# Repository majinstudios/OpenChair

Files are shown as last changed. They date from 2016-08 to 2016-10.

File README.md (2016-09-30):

# OpenChair

With OpenChair we want to create the first wheelchair development platform in which users can code or design the adaptations necessary to fit their needs.

In order to do so, we modified a manual wheelchair to convert it into an electric one, designed highly customizable armrests and developed a controller board with BLE to allow users to build and control the wheelchair in the manner that best suits them.

For further information and build instructions, please check [this page](https://hackaday.io/project/13347-openchair).

Licenses
---------
Software: GPL v3
Mechanical: Creative Commons Attribution-ShareAlike 4.0 International (CC BY-SA 4.0)

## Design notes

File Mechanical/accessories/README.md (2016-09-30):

# OpenChair: how to create a custom accessory
Inside the utilities folder you may find the FreeCad file (and also stl & step files) of both the male and female hitches needed to create custom accessories.

Using the female hitch, you can adapt the surface you want to the existing accessories.

With the male hitch, you can create a custom accessory that will fit the OpenChair armrest.

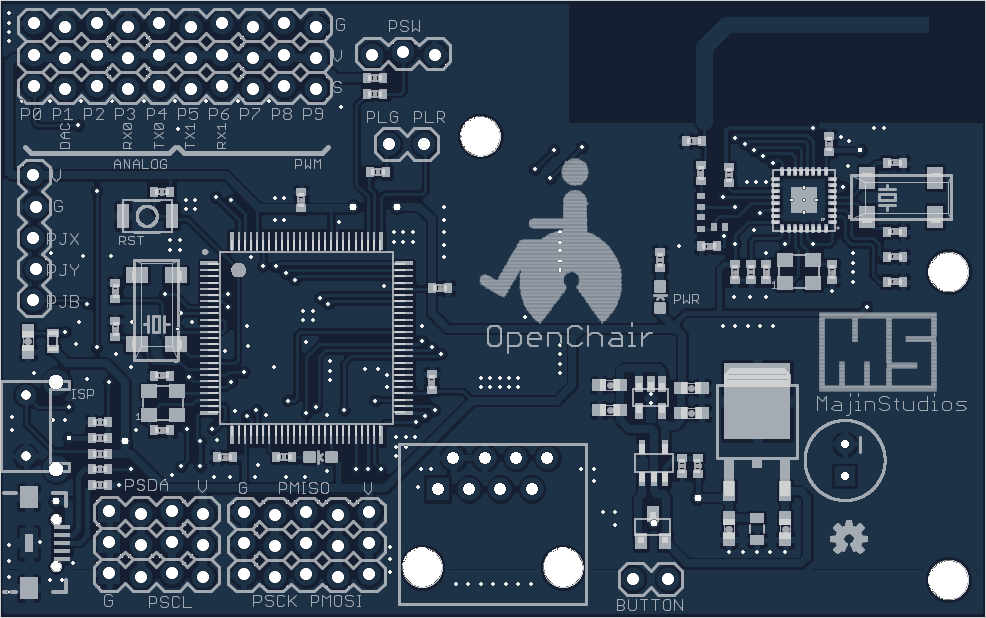
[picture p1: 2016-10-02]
Hardware/Silkscreen/OpenChair1_Top.png

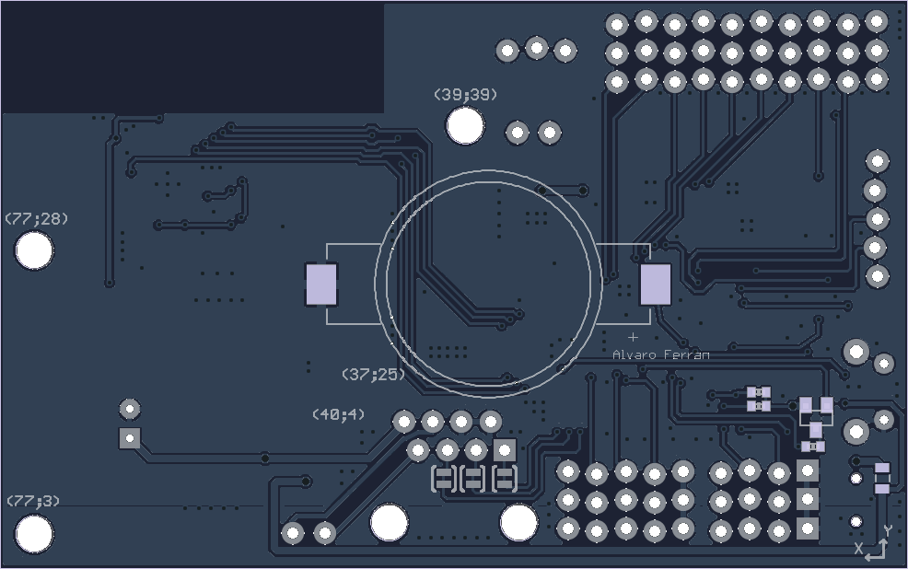
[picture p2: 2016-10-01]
Hardware/Silkscreen/OpenChair2_Bottom.png

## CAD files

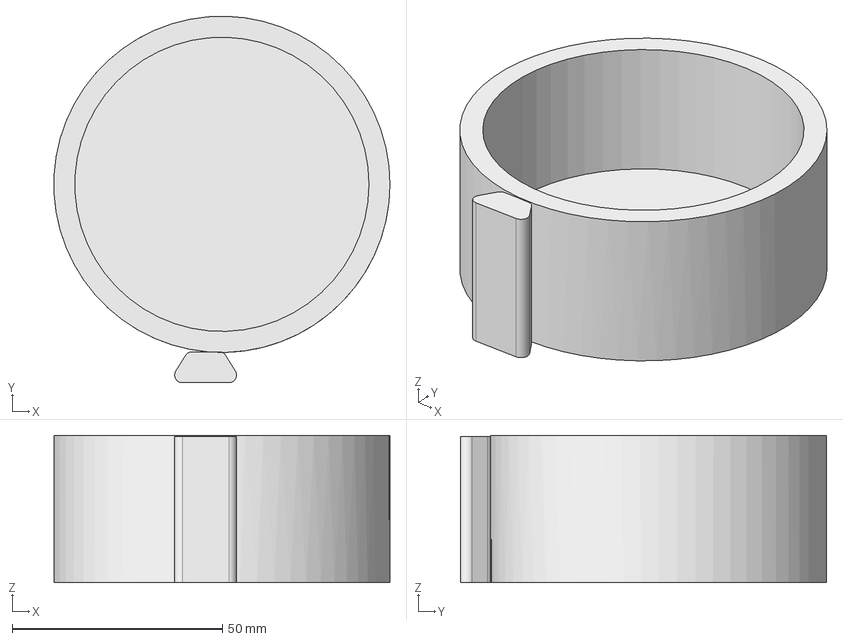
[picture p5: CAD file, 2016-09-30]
Mechanical/accessories/Can holder/can_holder.step
79.9 x 87.2 x 35.0 mm

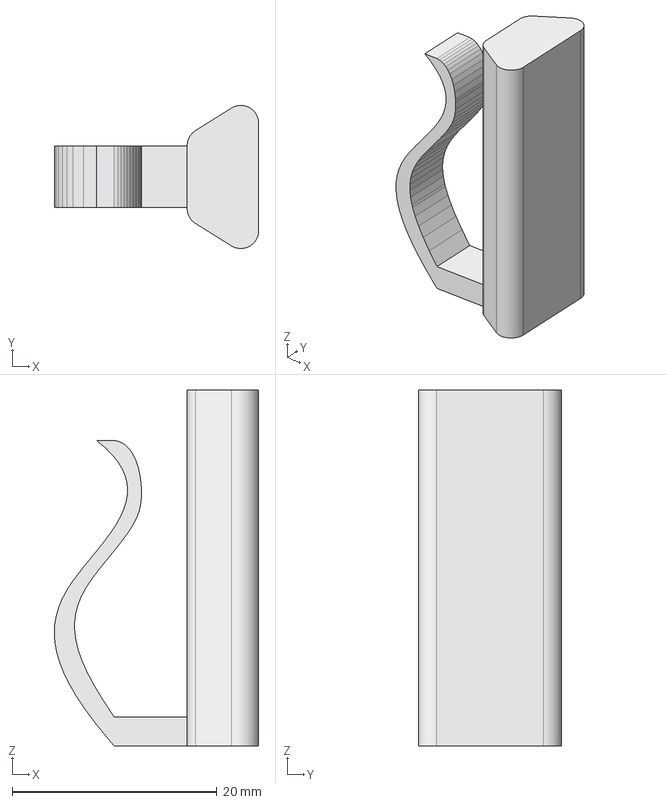
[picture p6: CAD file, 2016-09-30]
Mechanical/accessories/Clip/clip.step
20.0 x 14.0 x 34.8 mm

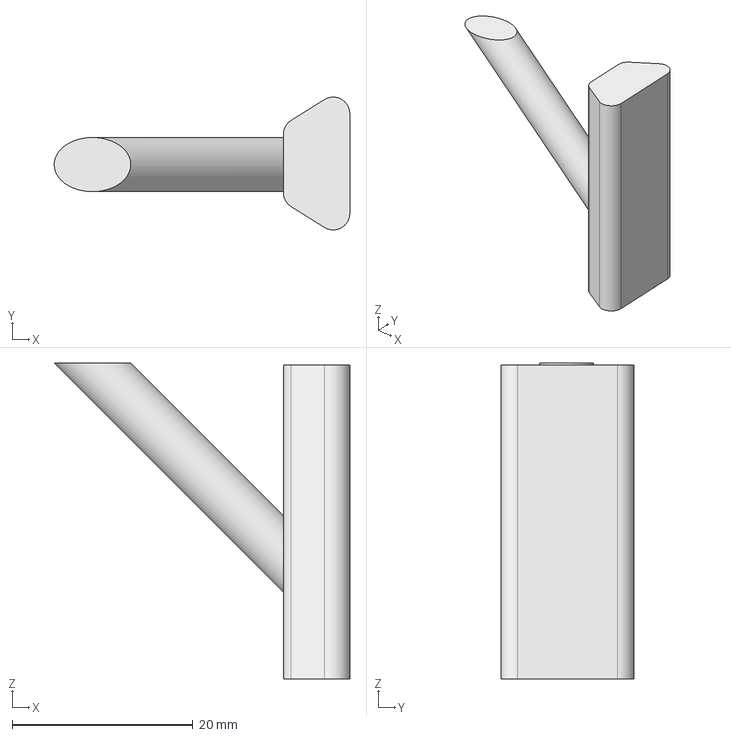
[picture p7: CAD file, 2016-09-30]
Mechanical/accessories/Hook/hook.step
32.7 x 14.7 x 35.0 mm

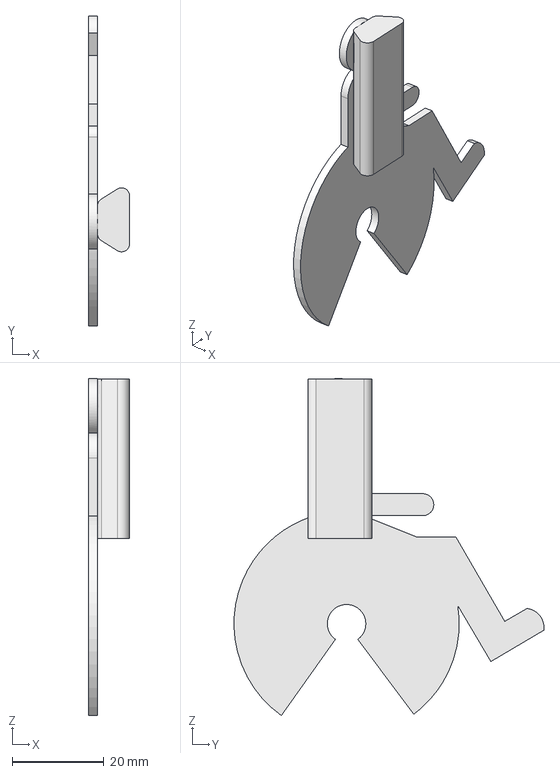
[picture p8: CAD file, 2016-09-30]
Mechanical/accessories/Logo accessory/logo.step
8.98 x 67.7 x 73.6 mm

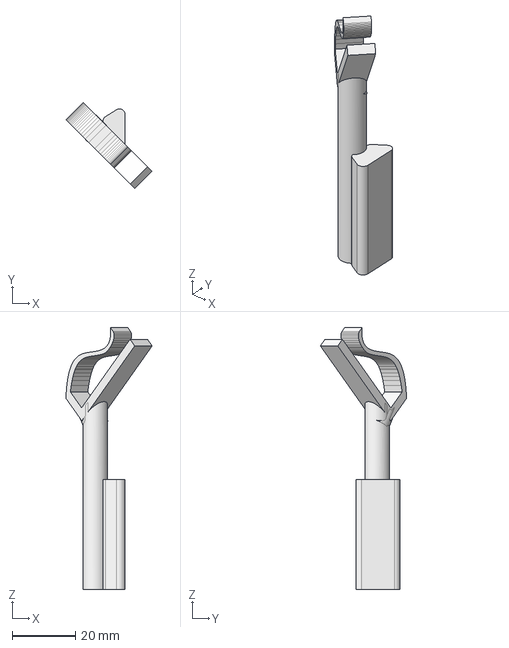
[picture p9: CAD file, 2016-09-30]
Mechanical/accessories/Mobile holder/mobile_holder.step
27.3 x 27.3 x 82.8 mm

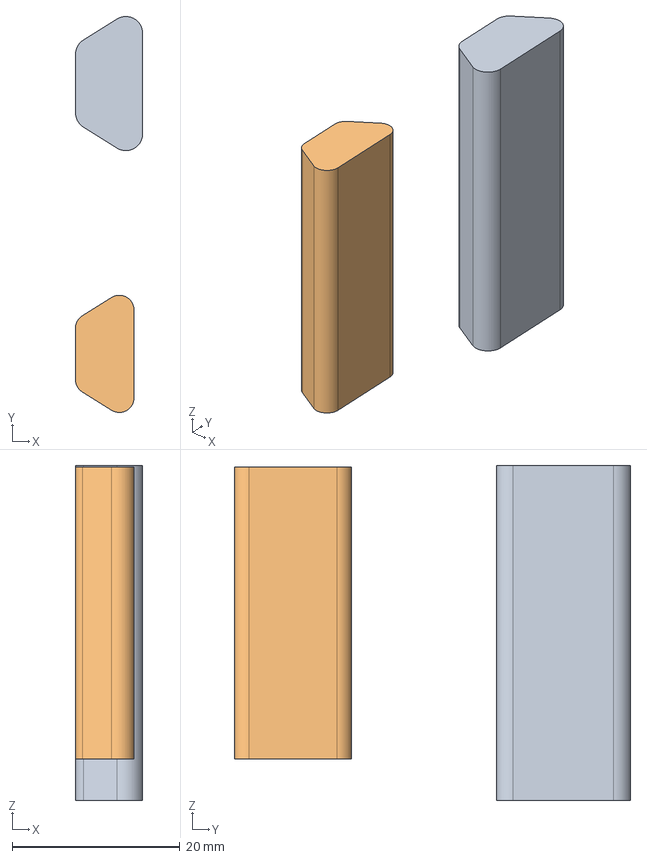
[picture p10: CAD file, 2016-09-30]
Mechanical/accessories/Utilities/Hitch_male_and_female.FCStd
8.02 x 47.2 x 40.0 mm
Hitch female
Hitch male

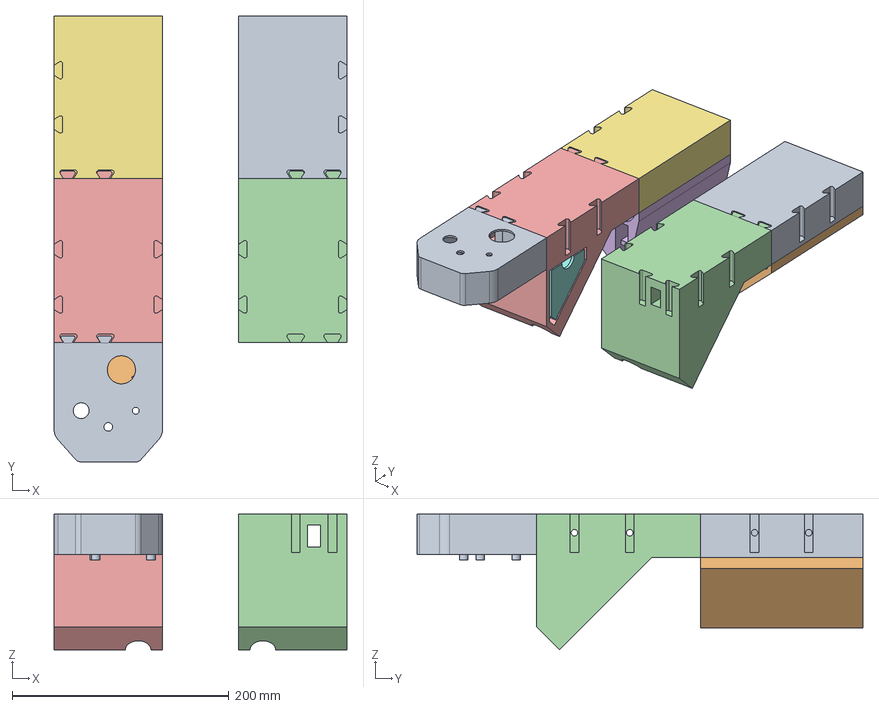
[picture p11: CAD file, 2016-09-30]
Mechanical/v0.0.3/armrests.FCStd
270.0 x 411.2 x 125.0 mm
Mirror of Clone of Upper armrest001
Mirror of Clone of Lower armrest with custom support001
Mirror of Clone of Drawer
Mirror of Clone of Curved armrest
Curved armrest
Lower armrest with custom support
Upper armrest
Drawer
Control panel nucleo
Joystick support plane

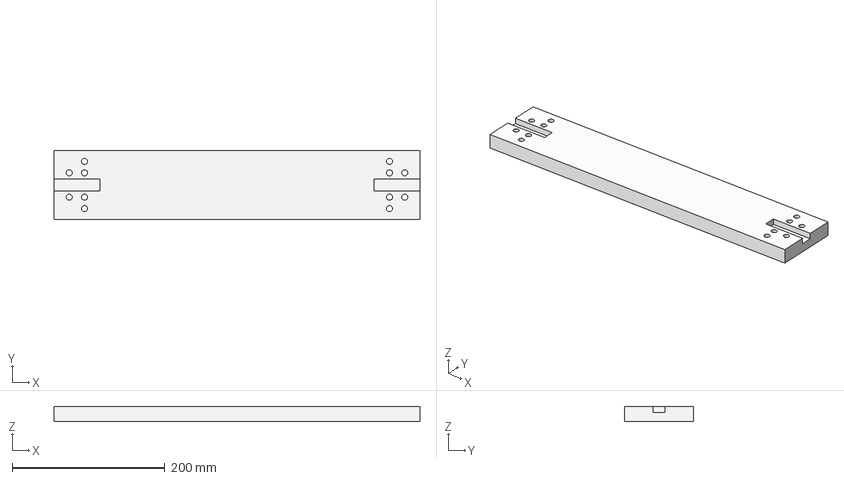
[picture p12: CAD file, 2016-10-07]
Mechanical/v0.0.3/STEP/wood_plank.step
480.0 x 90.0 x 20.0 mm

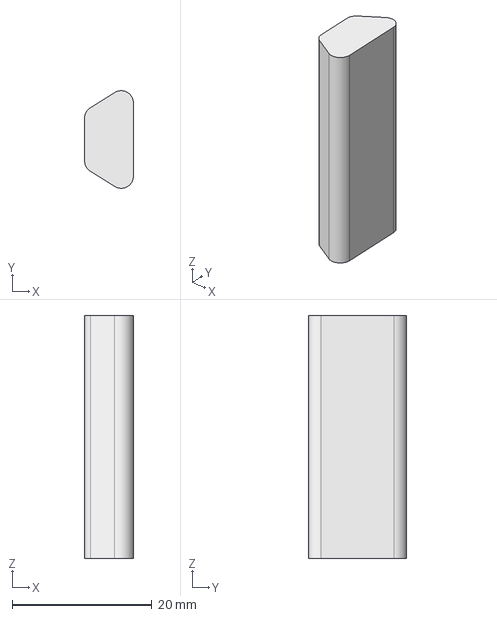
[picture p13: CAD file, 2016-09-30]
Mechanical/accessories/Utilities/male_hitch.step
6.99 x 14.0 x 34.8 mm

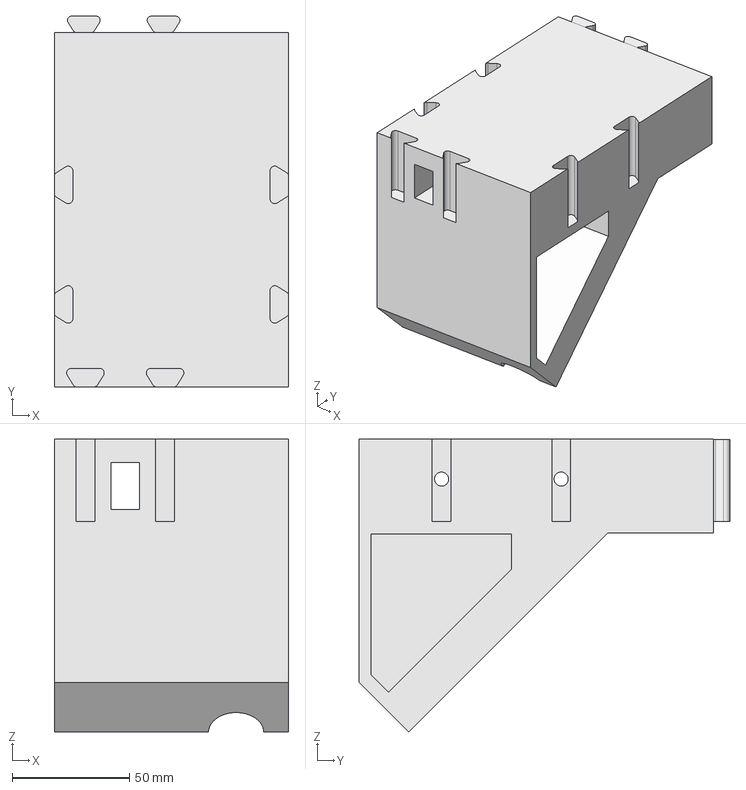
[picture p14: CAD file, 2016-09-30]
Mechanical/v0.0.3/STEP/armrest_right_003.step
100.0 x 158.1 x 125.0 mm

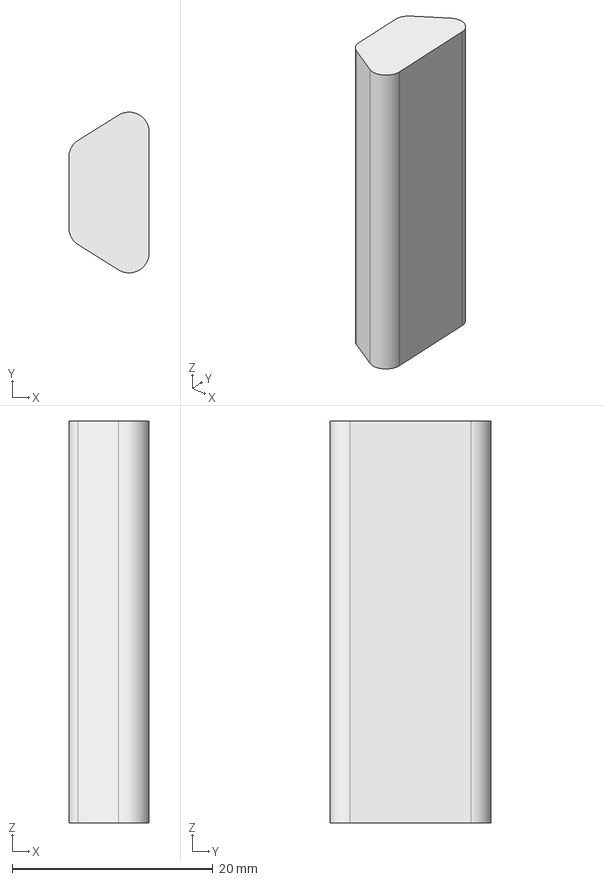
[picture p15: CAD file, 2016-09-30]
Mechanical/accessories/Utilities/female_hitch.step
8.00 x 16.0 x 40.0 mm

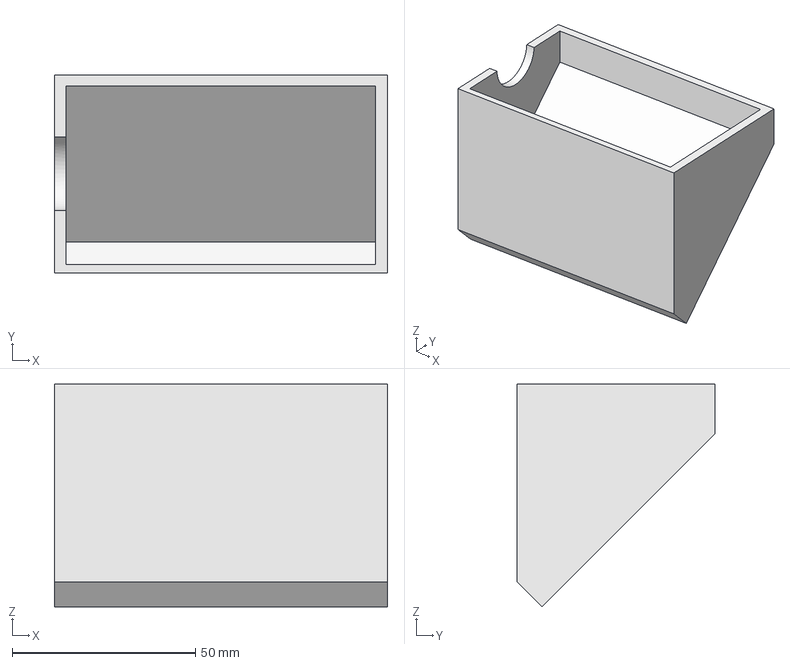
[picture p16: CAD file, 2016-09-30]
Mechanical/v0.0.3/STEP/armrest_left_drawer.step
90.9 x 54.0 x 60.8 mm

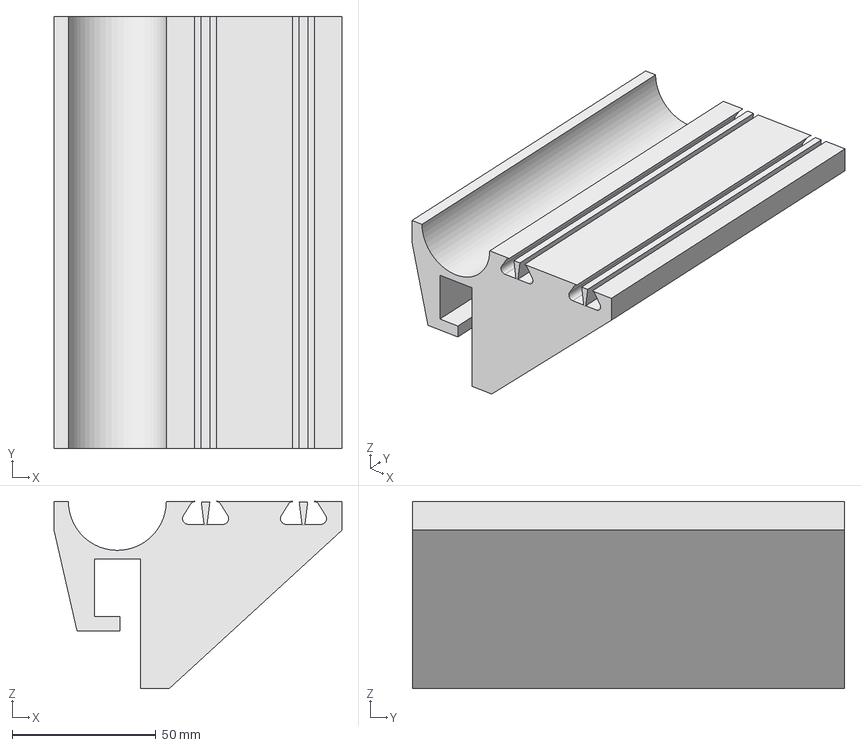
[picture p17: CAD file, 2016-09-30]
Mechanical/v0.0.3/STEP/armrest_left_002.step
100.0 x 150.0 x 65.0 mm

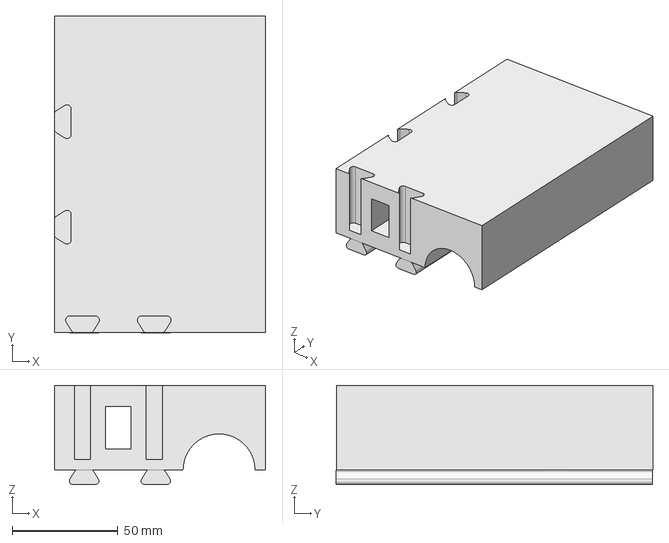
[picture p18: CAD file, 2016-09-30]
Mechanical/v0.0.3/STEP/armrest_right_001.step
100.0 x 150.0 x 47.0 mm

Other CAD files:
Mechanical/v0.0.3/STEP/armrest_right_drawer.step
Mechanical/v0.0.3/STEP/armrest_left_001.step
Mechanical/v0.0.3/STEP/armrest_left_003.step
Mechanical/v0.0.3/STEP/armrest_right_002.step
Mechanical/accessories/Can holder/can_holder.FCStd
Mechanical/accessories/Can holder/can_holder.stl
Mechanical/accessories/Clip/clip.FCStd
Mechanical/accessories/Clip/clip.stl
Mechanical/accessories/Hook/hook.FCStd
Mechanical/accessories/Hook/hook.stl
Mechanical/accessories/Logo accessory/logo.FCStd
Mechanical/accessories/Logo accessory/logo.stl
Mechanical/accessories/Mobile holder/mobile_holder.FCStd
Mechanical/accessories/Mobile holder/mobile_holder.stl
Mechanical/accessories/Utilities/female_hitch.stl
Mechanical/accessories/Utilities/male_hitch.stl
Mechanical/v0.0.1/hoverboard_fastener.FCStd
Mechanical/v0.0.2/hoverboard_case.FCStd
Mechanical/v0.0.3/STL/armrest_left_001.stl
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

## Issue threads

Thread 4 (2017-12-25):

Need Help

Tirta01, 2017-12-25:
Hi, I am really curious about this. I have do corrections from wiring, reinstall platformio, try to flash code on different pc, and many more, but i still fail. The thing that still makes me the doubt, is the missing of dependencies, but I cant find what it is and cant get a solution on the internet.

Can you share the firmware.bin ready from .pioenvs\nucleo_f446re\firmware.bin, so I can flash it to the board using the st-link utility. Please your help to give me one more chance to make this work. If this still fails, I'll be sure my board is broken, maybe the path is disconnected from the chip. thank a lot.

Closed 2018-01-14.

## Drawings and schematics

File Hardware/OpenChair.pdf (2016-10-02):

# NXP_LPC1768_FBD100

U1

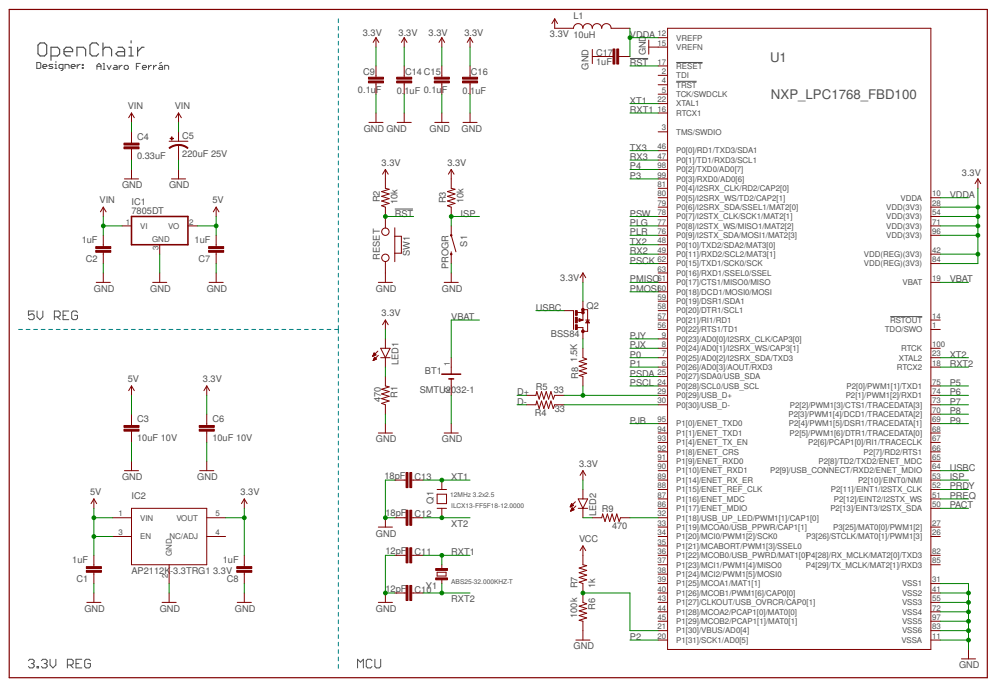
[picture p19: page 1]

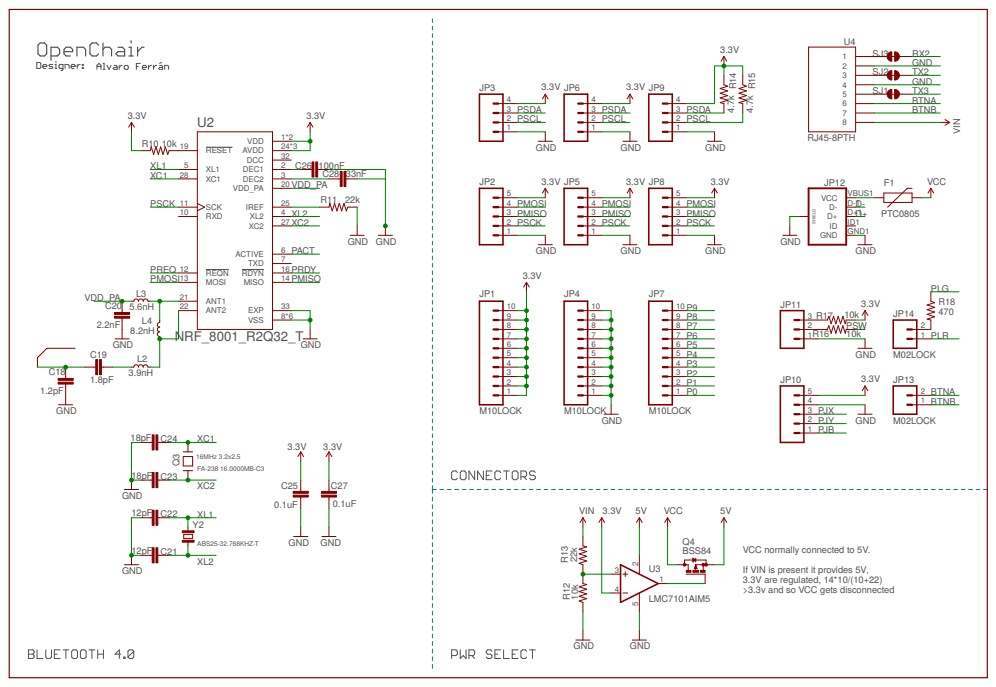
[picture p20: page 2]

3 PSDA | 3 PSDA | 3 PSDA
2 PSCL | 2 PSCL | 2 PSCL

VCC normally connected to 5V.
If VIN is present it provides 5V, 3.3V are regulated, 14*10/(10+22)
>3.3v and so VCC gets disconnected

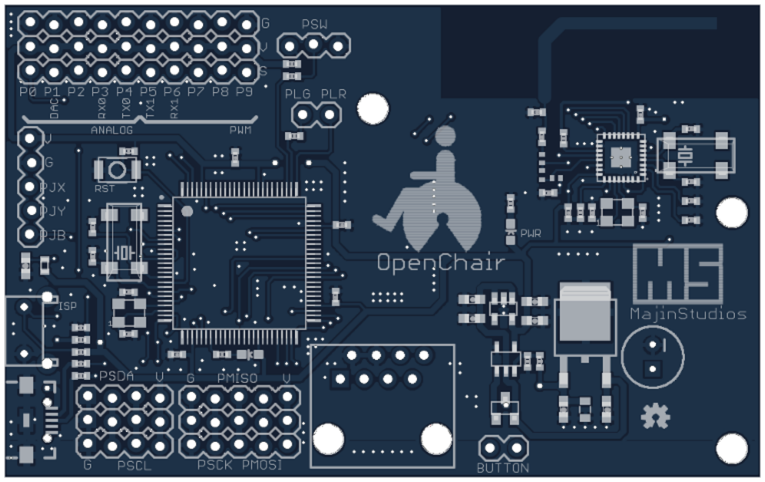
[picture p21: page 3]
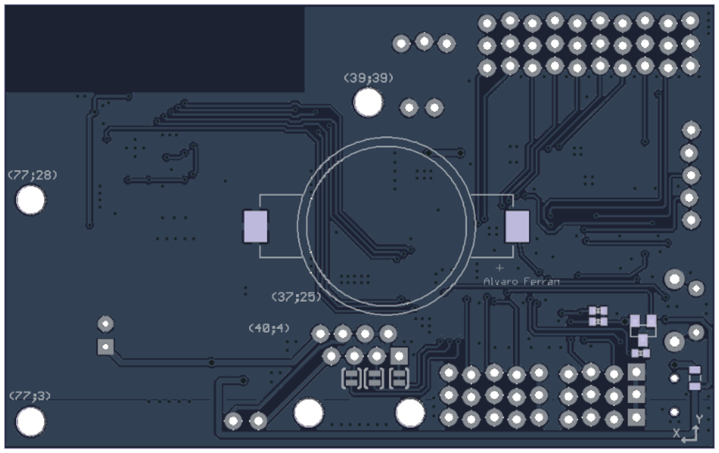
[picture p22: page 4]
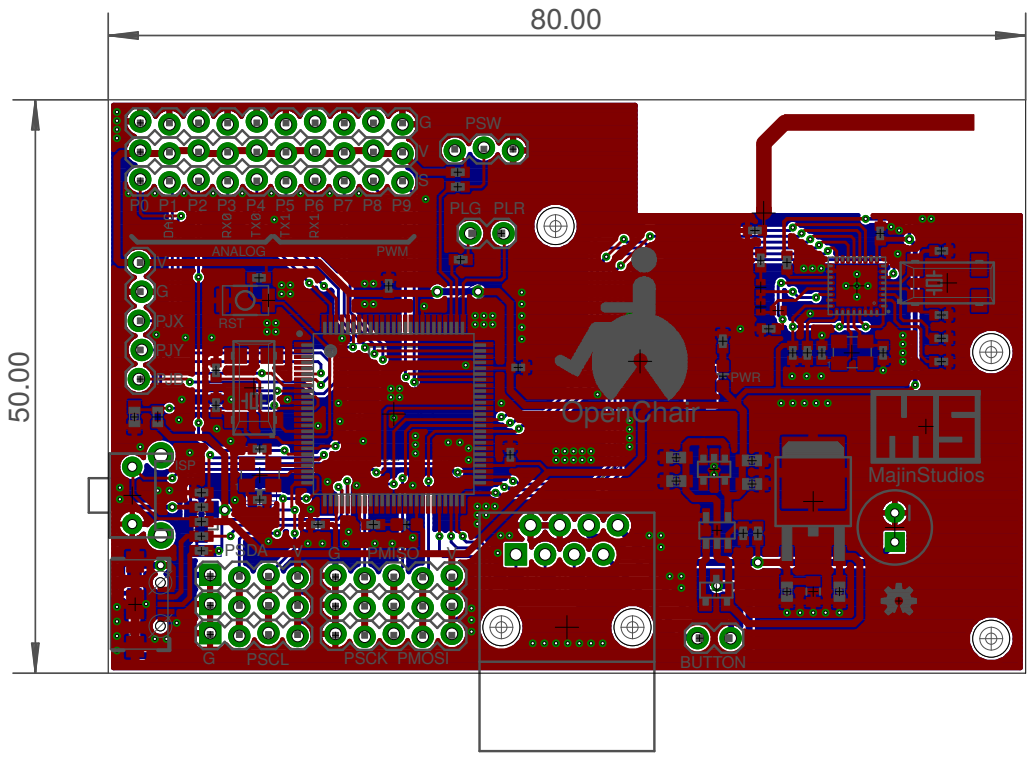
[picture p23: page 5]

ANALOG VG | PWM

RST

PWR

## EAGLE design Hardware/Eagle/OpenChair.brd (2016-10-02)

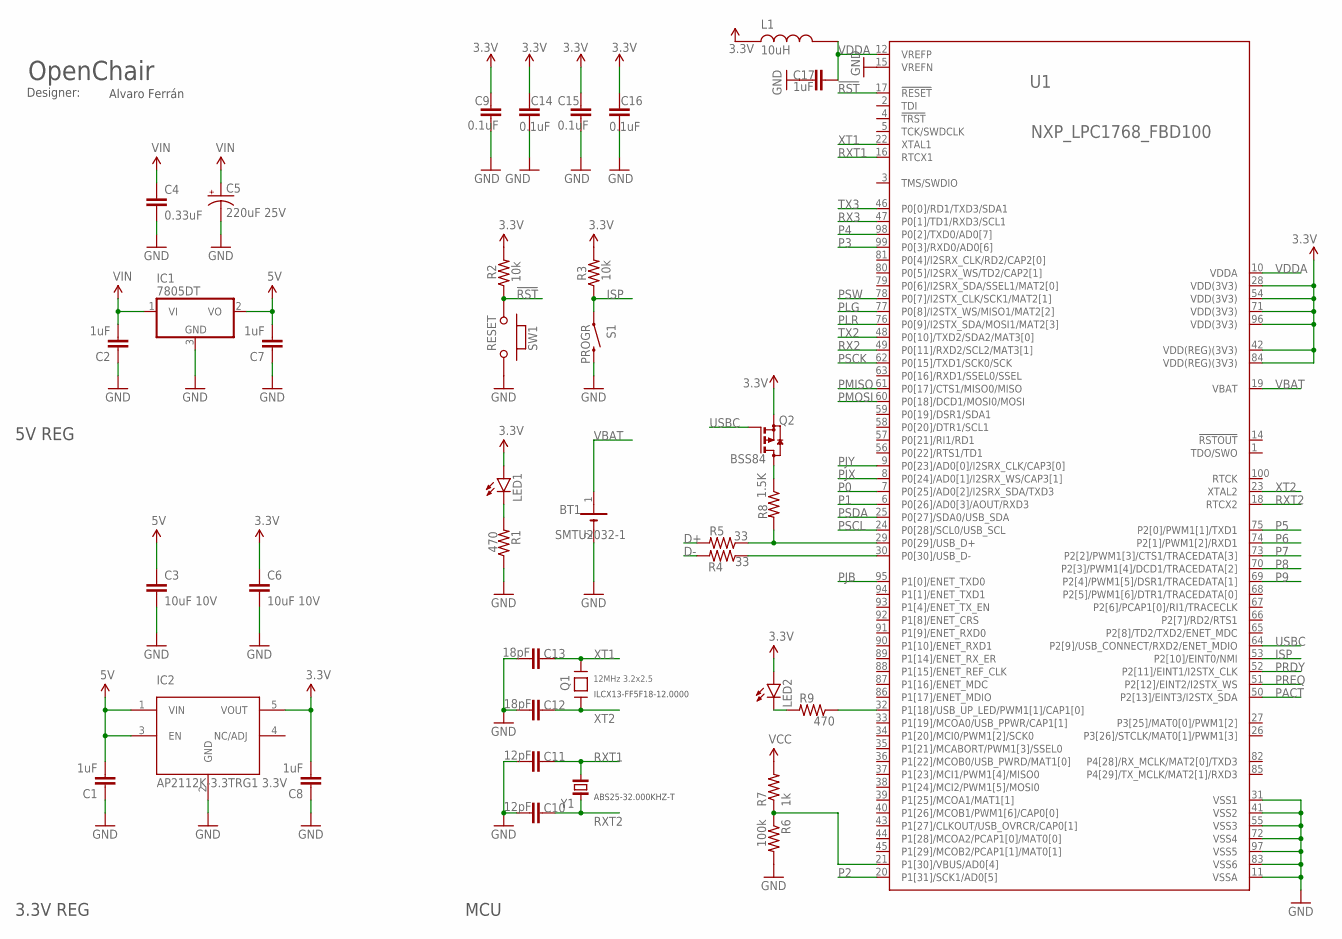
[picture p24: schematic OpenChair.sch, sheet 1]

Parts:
BT1: SMTU2032-1; RENATA_SMTU2032-1
C1, C2, C7, C8, C17: 1uF; 0603-CAP
C3, C6: 10uF 10V; 0603-CAP
C4: 0.33uF; 0805
C5: 220uF 25V; CPOL-RADIAL-100UF-25V
C9, C14, C15, C16: 0.1uF; 0402-CAP
C10, C11: 12pF; 0402-CAP
C12, C13: 18pF; 0402-CAP
IC1: 7805DT; TO252
IC2: AP2112K-3.3TRG1 3.3V; SOT23-5
L1: 10uH; L0603
LED1, LED2: LED0603; LED-0603
Q1: 12MHz 3.2x2.5; CRYSTAL_3.2X2.5
Q2: BSS84; SOT23
R1, R9: 470; 0402-RES
R2, R3: 10k; 0402-RES
R4, R5: 33; 0402-RES
R6: 100k; 0402-RES
R7: 1k; 0402-RES
R8: 1.5K; 0402-RES
S1: PROGR; TACTILE-PTH-SIDEEZ
SW1: RESET; 157SW
U1: NXP_LPC1768_FBD100; QFP50P1600X1600X160-100N
Y1: ABS25

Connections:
3.3V: C6.1, C8.2, C9.1, C14.1, C15.1, C16.1, IC2.5 (VOUT), L1.P$1, LED1.A, LED2.A, Q2.2 (S), R2.2, R3.2, U1.28 (VDD(3V3)), U1.42 (VDD(REG)(3V3)), U1.54 (VDD(3V3)), U1.71 (VDD(3V3)), U1.84 (VDD(REG)(3V3)), U1.96 (VDD(3V3)); also elsewhere on the board
5V: C1.2, C3.1, C7.2, IC1.2 (VO), IC2.1 (VIN), IC2.3 (EN); also elsewhere on the board
!RST: R2.1, SW1.1, U1.17 (!RESET)
D+: R5.2; also elsewhere on the board
D-: R4.2; also elsewhere on the board
GND: BT1.2 (-), C1.1, C2.1, C3.2, C4.2, C5.2 (-), C6.2, C7.1, C8.1, C9.2, C10.2, C11.2, C12.2, C13.2, C14.2, C15.2, C16.2, C17.1, IC1.3 (GND), IC2.2 (GND), R1.1, R6.2, S1.2, SW1.2, U1.11 (VSSA), U1.15 (VREFN), U1.31 (VSS1), U1.41 (VSS2), U1.55 (VSS3), U1.72 (VSS4), U1.83 (VSS6), U1.97 (VSS5); also elsewhere on the board
ISP: R3.1, S1.1, U1.53 (P2[10]/EINT0/NMI)
unnamed: LED1.C, R1.2
unnamed: R6.1, R7.1, U1.21 (P1[30]/VBUS/AD0[4])
unnamed: R5.1, R8.2, U1.29 (P0[29]/USB_D+)
unnamed: R9.1, U1.32 (P1[18]/USB_UP_LED/PWM1[1]/CAP1[0])
unnamed: LED2.C, R9.2
unnamed: R4.1, U1.30 (P0[30]/USB_D-)
unnamed: Q2.3 (D), R8.1
P0: U1.7 (P0[25]/AD0[2]/I2SRX_SDA/TXD3); also elsewhere on the board
P1: U1.6 (P0[26]/AD0[3]/AOUT/RXD3); also elsewhere on the board
P2: U1.20 (P1[31]/SCK1/AD0[5]); also elsewhere on the board
P3: U1.99 (P0[3]/RXD0/AD0[6]); also elsewhere on the board
P4: U1.98 (P0[2]/TXD0/AD0[7]); also elsewhere on the board
P5: U1.75 (P2[0]/PWM1[1]/TXD1); also elsewhere on the board
P6: U1.74 (P2[1]/PWM1[2]/RXD1); also elsewhere on the board
P7: U1.73 (P2[2]/PWM1[3]/CTS1/TRACEDATA[3]); also elsewhere on the board
P8: U1.70 (P2[3]/PWM1[4]/DCD1/TRACEDATA[2]); also elsewhere on the board
P9: U1.69 (P2[4]/PWM1[5]/DSR1/TRACEDATA[1]); also elsewhere on the board
PACT: U1.50 (P2[13]/EINT3/I2STX_SDA); also elsewhere on the board
PJB: U1.95 (P1[0]/ENET_TXD0); also elsewhere on the board
PJX: U1.8 (P0[24]/AD0[1]/I2SRX_WS/CAP3[1]); also elsewhere on the board
PJY: U1.9 (P0[23]/AD0[0]/I2SRX_CLK/CAP3[0]); also elsewhere on the board
PLG: U1.77 (P0[8]/I2STX_WS/MISO1/MAT2[2]); also elsewhere on the board
PLR: U1.76 (P0[9]/I2STX_SDA/MOSI1/MAT2[3]); also elsewhere on the board
PMISO: U1.61 (P0[17]/CTS1/MISO0/MISO); also elsewhere on the board
PMOSI: U1.60 (P0[18]/DCD1/MOSI0/MOSI); also elsewhere on the board
PRDY: U1.52 (P2[11]/EINT1/I2STX_CLK); also elsewhere on the board
PREQ: U1.51 (P2[12]/EINT2/I2STX_WS); also elsewhere on the board
PSCK: U1.62 (P0[15]/TXD1/SCK0/SCK); also elsewhere on the board
PSCL: U1.24 (P0[28]/SCL0/USB_SCL); also elsewhere on the board
PSDA: U1.25 (P0[27]/SDA0/USB_SDA); also elsewhere on the board
PSW: U1.78 (P0[7]/I2STX_CLK/SCK1/MAT2[1]); also elsewhere on the board
RX2: U1.49 (P0[11]/RXD2/SCL2/MAT3[1]); also elsewhere on the board
RX3: U1.47 (P0[1]/TD1/RXD3/SCL1)
RXT1: C11.1, U1.16 (RTCX1), Y1.1
RXT2: C10.1, U1.18 (RTCX2), Y1.4 (2)
TX2: U1.48 (P0[10]/TXD2/SDA2/MAT3[0]); also elsewhere on the board
TX3: U1.46 (P0[0]/RD1/TXD3/SDA1); also elsewhere on the board
USBC: Q2.1 (G), U1.64 (P2[9]/USB_CONNECT/RXD2/ENET_MDIO)
VBAT: BT1.1 (+), U1.19 (VBAT)
VCC: R7.2; also elsewhere on the board
VDDA: C17.2, L1.P$2, U1.10 (VDDA), U1.12 (VREFP)
VIN: C2.2, C4.1, C5.1 (+), IC1.1 (VI); also elsewhere on the board
XT1: C13.1, Q1.3, U1.22 (XTAL1)
XT2: C12.1, Q1.1, U1.23 (XTAL2)

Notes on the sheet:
3.3V REG
OpenChair
Designer:
Alvaro Ferrán
5V REG
MCU
ILCX13-FF5F18-12.0000
ABS25-32.000KHZ-T

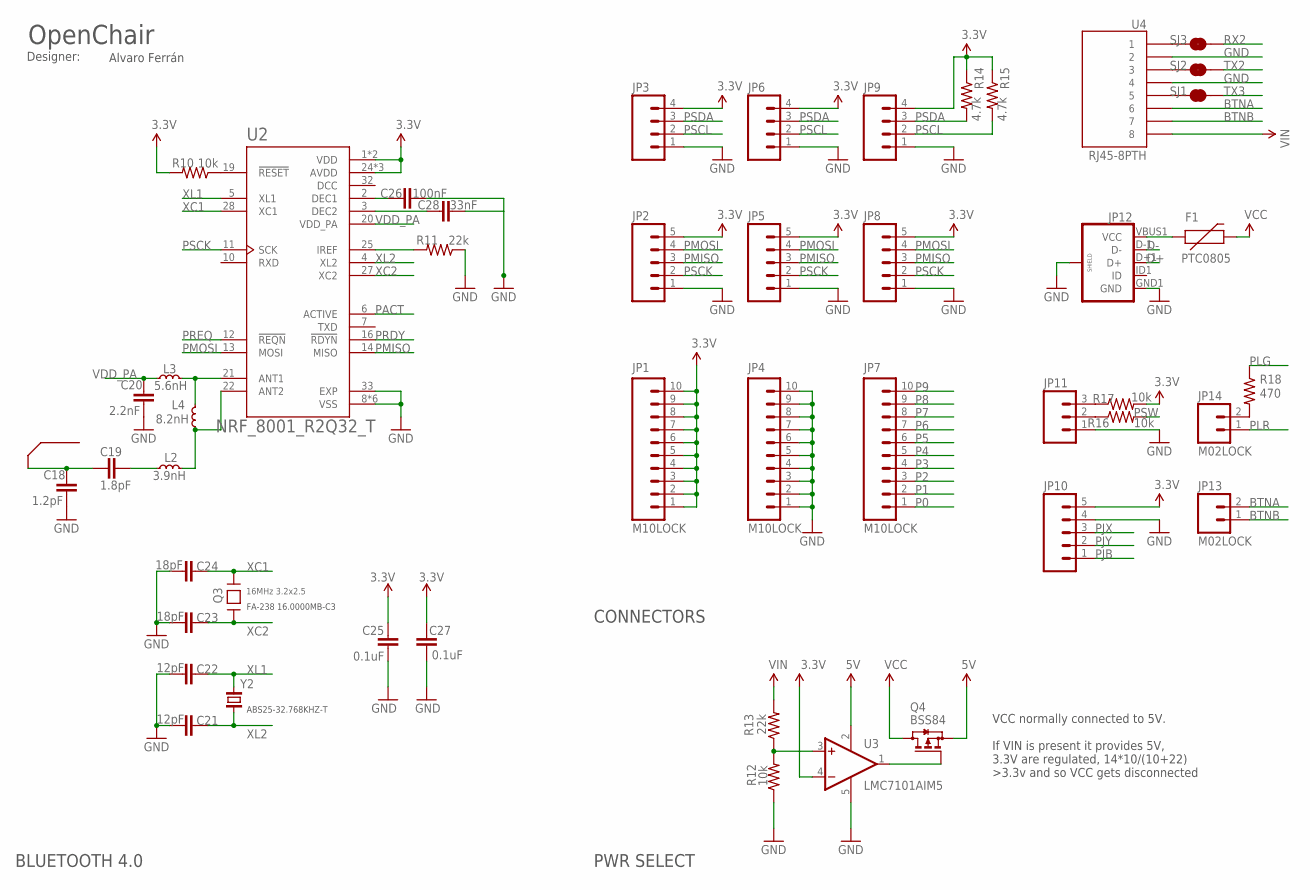
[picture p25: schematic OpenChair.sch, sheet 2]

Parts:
ANT1: NRF_ANTENNA
C18: 1.2pF; 0402-CAP
C19: 1.8pF; 0402-CAP
C20: 2.2nF; 0402-CAP
C21, C22: 12pF; 0402-CAP
C23, C24: 18pF; 0402-CAP
C25, C27: 0.1uF; 0402-CAP
C26: 100nF; 0402-CAP
C28: 33nF; 0402-CAP
F1: PTC0805; 0805
JP1, JP4, JP7: M10LOCK; 1X10_LOCK
JP2, JP5, JP8, JP10: M05LOCK; 1X05_LOCK
JP3, JP6, JP9: M04LOCK; 1X04_LOCK
JP11: M03LOCK; 1X03_LOCK
JP12: USB_MICROB_PLUGCONN-11752; USB-B-MICRO-SMD_V03
JP13, JP14: M02LOCK; 1X02_LOCK
L2: 3.9nH; 0402
L3: 5.6nH; 0402
L4: 8.2nH; 0402
Q3: 16MHz 3.2x2.5; CRYSTAL_3.2X2.5
Q4: BSS84; SOT23
R10, R12, R16, R17: 10k; 0402-RES
R11, R13: 22k; 0402-RES
R14, R15: 4.7k; 0402-RES
R18: 470; 0402-RES
SJ1, SJ2, SJ3: JUMPER-PAD-2-NC_BY_TRACE; PAD-JUMPER-2-NC_BY_TRACE_YES_SILK
U2: NRF_8001_R2Q32_T; QFN50P500X500X90-33N
U3: LMC7101AIM5; SOT23-5
U4: RJ45-8PTH; RJ45-8
Y2: ABS25-32.768kHz; ABS25

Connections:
3.3V: C25.1, C27.1, JP1.1, JP1.2, JP1.3, JP1.4, JP1.5, JP1.6, JP1.7, JP1.8, JP1.9, JP1.10, JP2.5, JP3.4, JP5.5, JP6.4, JP8.5, JP9.4, JP10.5, R10.2, R14.1, R15.1, R17.2, U2.1 (VDD), U2.9 (VDD), U2.24 (AVDD), U2.26 (AVDD), U2.29 (AVDD), U3.4 (-IN); also elsewhere on the board
5V: Q4.2 (S), U3.2 (V+); also elsewhere on the board
BTNA: JP13.2, U4.6
BTNB: JP13.1, U4.7
D+: JP12.D+1 (D+); also elsewhere on the board
D-: JP12.D-1 (D-); also elsewhere on the board
DCC: U2.32 (DCC)
GND: C18.2, C20.2, C21.2, C22.2, C23.2, C24.2, C25.2, C26.1, C27.2, C28.1, JP2.1, JP3.1, JP4.1, JP4.2, JP4.3, JP4.4, JP4.5, JP4.6, JP4.7, JP4.8, JP4.9, JP4.10, JP5.1, JP6.1, JP8.1, JP9.1, JP10.4, JP11.1, JP12.GND1 (GND), JP12.SHIELD1 (SHIELD), JP12.SHIELD2 (SHIELD), JP12.SHIELD3 (SHIELD), R11.1, R12.1, U2.8 (VSS), U2.17 (VSS), U2.18 (VSS), U2.23 (VSS), U2.30 (VSS), U2.31 (VSS), U2.33 (EXP), U3.5 (V-), U4.2, U4.4; also elsewhere on the board
unnamed: JP14.2, R18.2
unnamed: SJ3.1, U4.1
unnamed: SJ2.1, U4.3
unnamed: SJ1.1, U4.5
unnamed: F1.1, JP12.VBUS1 (VCC)
unnamed: JP11.2, R16.1
unnamed: JP11.3, R17.1
unnamed: Q4.1 (G), U3.1 (OUT)
unnamed: R12.2, R13.1, U3.3 (+IN)
unnamed: R11.2, U2.25 (IREF)
unnamed: C26.2, U2.2 (DEC1)
unnamed: C28.2, U2.3 (DEC2)
unnamed: R10.1, U2.19 (!RESET)
unnamed: L2.2, L4.1, U2.22 (ANT2)
unnamed: L3.2, L4.2, U2.21 (ANT1)
unnamed: C19.1, L2.1
unnamed: ANT1.P$1, C18.1, C19.2
P0: JP7.1; also elsewhere on the board
P1: JP7.2; also elsewhere on the board
P2: JP7.3; also elsewhere on the board
P3: JP7.4; also elsewhere on the board
P4: JP7.5; also elsewhere on the board
P5: JP7.6; also elsewhere on the board
P6: JP7.7; also elsewhere on the board
P7: JP7.8; also elsewhere on the board
P8: JP7.9; also elsewhere on the board
P9: JP7.10; also elsewhere on the board
PACT: U2.6 (ACTIVE); also elsewhere on the board
PJB: JP10.1; also elsewhere on the board
PJX: JP10.3; also elsewhere on the board
PJY: JP10.2; also elsewhere on the board
PLG: R18.1; also elsewhere on the board
PLR: JP14.1; also elsewhere on the board
PMISO: JP2.3, JP5.3, JP8.3, U2.14 (MISO); also elsewhere on the board
PMOSI: JP2.4, JP5.4, JP8.4, U2.13 (MOSI); also elsewhere on the board
PRDY: U2.16 (!RDYN); also elsewhere on the board
PREQ: U2.12 (!REQN); also elsewhere on the board
PSCK: JP2.2, JP5.2, JP8.2, U2.11 (SCK); also elsewhere on the board
PSCL: JP3.2, JP6.2, JP9.2, R15.2; also elsewhere on the board
PSDA: JP3.3, JP6.3, JP9.3, R14.2; also elsewhere on the board
PSW: R16.2; also elsewhere on the board
RX2: SJ3.2; also elsewhere on the board
TX2: SJ2.2; also elsewhere on the board
TX3: SJ1.2; also elsewhere on the board
VCC: F1.2, Q4.3 (D); also elsewhere on the board
VDD_PA: C20.1, L3.1, U2.20 (VDD_PA)
VIN: R13.2, U4.8; also elsewhere on the board
XC1: C24.1, Q3.3, U2.28 (XC1)
XC2: C23.1, Q3.1, U2.27 (XC2)
XL1: C22.1, U2.5 (XL1), Y2.4 (2)
XL2: C21.1, U2.4 (XL2), Y2.1

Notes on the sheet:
OpenChair
Designer:
Alvaro Ferrán
CONNECTORS
VCC normally connected to 5V. If VIN is present it provides 5V, 3.3V are regulated, 14*10/(10+22) >3.3v and so VCC gets disconnected
PWR SELECT
ABS25-32.768KHZ-T
FA-238 16.0000MB-C3
BLUETOOTH 4.0

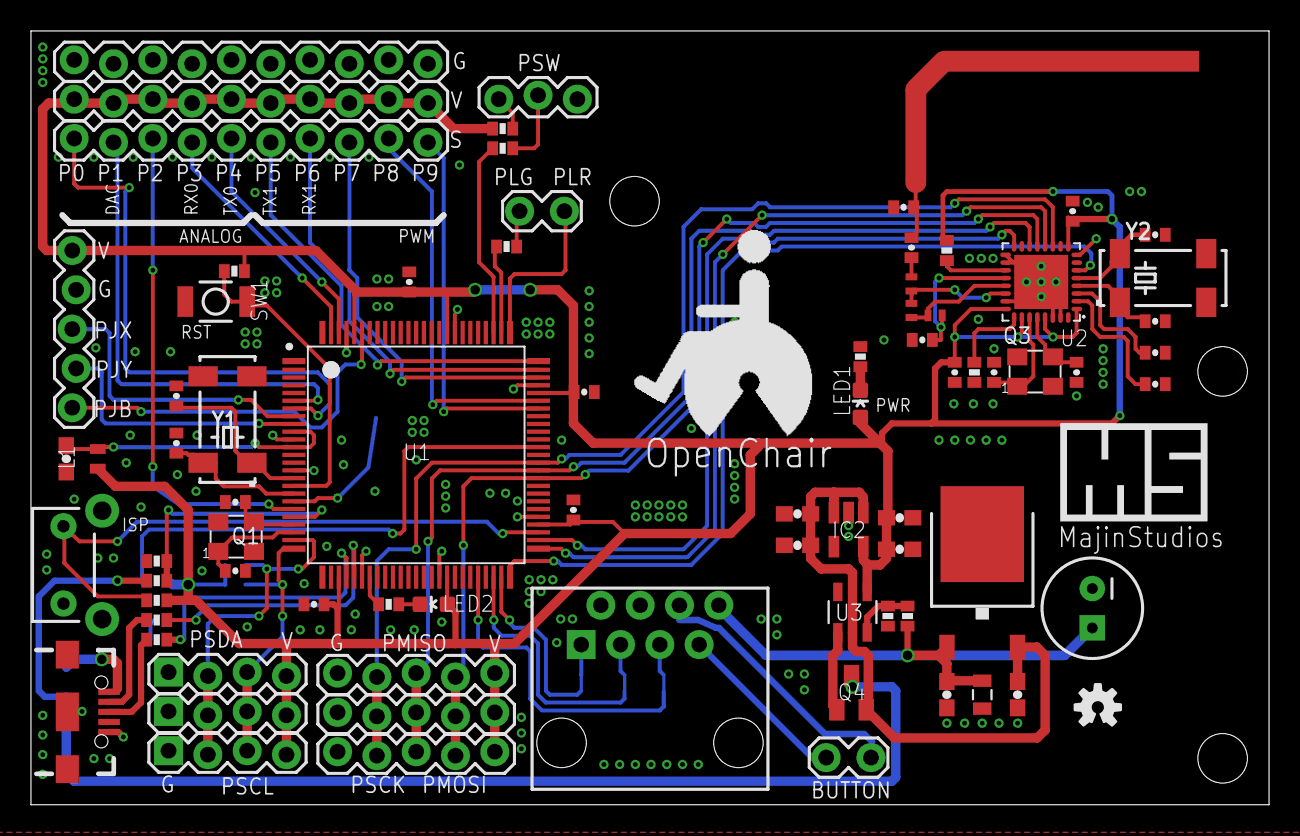
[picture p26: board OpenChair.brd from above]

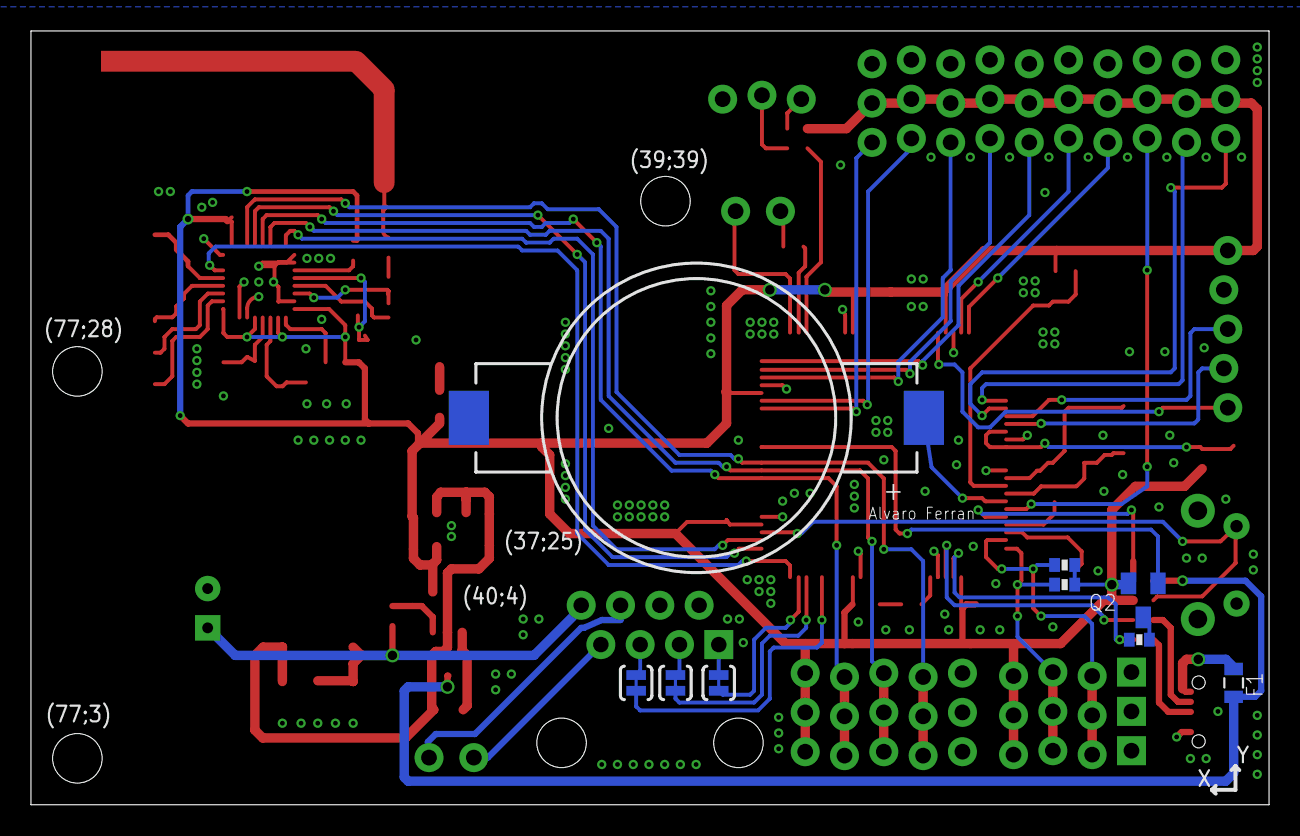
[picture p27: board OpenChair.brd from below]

Board: 2 copper layers, 80.0 x 50.0 mm, 89 parts (9 on the bottom side), 74 nets.

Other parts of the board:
U$1: MAJINSTUDIOS
U$2: OPENCHAIR2
U$3: OSHW-LOGO-S

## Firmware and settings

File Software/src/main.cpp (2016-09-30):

#include "mbed.h"
#include "OpenChair.h"

AnalogIn potX(PA_0);
AnalogIn potY(PA_1);
Serial pc(SERIAL_TX, SERIAL_RX);
OpenChair chair(PC_12,PD_2,PC_10,PC_11,60,150); //50,150

int main() {

    pc.baud(115200);
    double valueX;
    double valueY;

    while (1){
      valueX= (double) (potX.read()*2-1);
      valueY= (double) (potY.read()*2-1);

      chair.drive(valueX, valueY, 1);
      wait_ms(50);
    }
}

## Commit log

2016-09-05 Added the armrest 3D files and modular hitches for accessories
    [armrest.FCStd, hitch_female_001.stl, hitch_female_002.stl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]
2016-09-06 New armrest version taking into account the chairs inner space. Hoverboard fastener v0.0.1
    [armrest_thick.FCStd, armrest_thin.FCStd, fastener_001.stl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]
2016-09-10 Added hoverboard fastener system and improved armrest_thin features
    [armrest_thin.FCStd, fastener_001.stl, fastener_002.stl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]
2016-09-10 Modified joystick control so it works with this board
2016-09-18 Changes in design, backup working demo sw
    [armrest_thin.FCStd, hoverboard_case.FCStd, hoverboard_fastener.FCStd]
2016-09-21 OpenChair code fully working!! :)
    [armrest_thin.FCStd]
2016-09-30 Maker faire small changes in code, design & logos
    [armrest_thin.FCStd, card_holder.FCStd]
2016-09-30 Reordered Mechanical part, updated READMEs and LICENCEs and cleaned up Software part
    [Hitch_male_and_female.FCStd, armrest_left_001.step, armrest_left_001.stl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]
2016-10-01 OpenChair board added
    [OpenChair.brd, OpenChair.sch]
2016-10-02 Added Gerber RS274X files and updated PDF
    [OpenChair.brd, OpenChair.sch]
2016-10-07 Added wood plank 3D design
    [wood_plank.FCStd, wood_plank.step, wood_plank.stl]

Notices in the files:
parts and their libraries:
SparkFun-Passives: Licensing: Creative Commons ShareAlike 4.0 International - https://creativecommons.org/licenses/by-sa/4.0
